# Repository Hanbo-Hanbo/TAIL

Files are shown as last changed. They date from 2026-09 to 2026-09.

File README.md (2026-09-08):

# TAIL

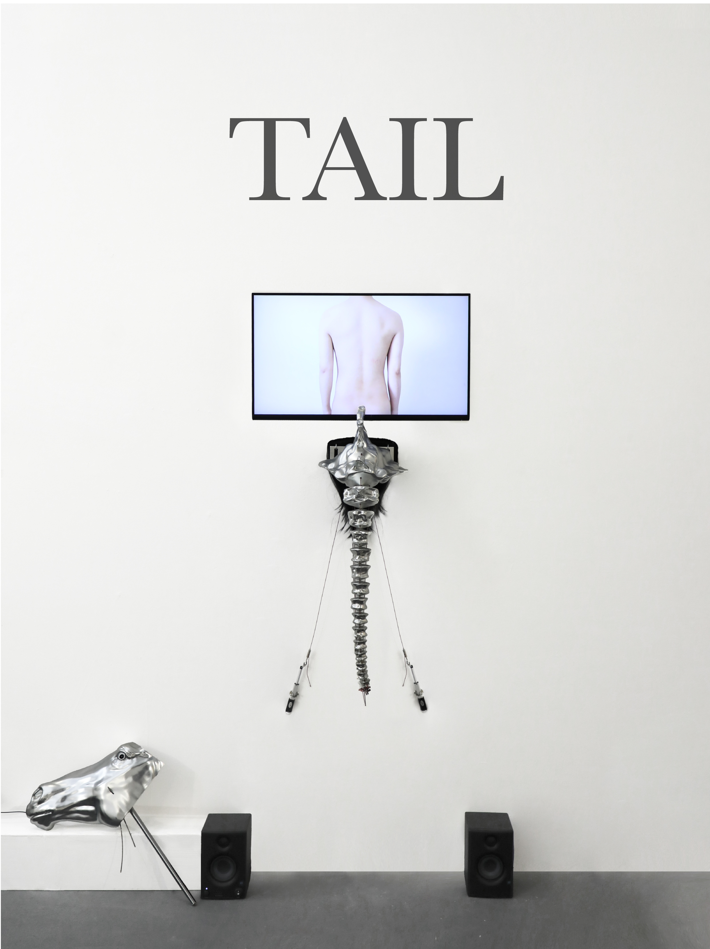
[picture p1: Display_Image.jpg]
TAIL installation


video link：https://youtu.be/1DqyYlydZfU

TAIL is a critical media art project that explores the power dynamics between technological systems and human subjectivity. The project consists of two parts: a live performance with a wearable device and an interactive physical installation.

The research motivation of this project is to ask: in a system that pursues extreme efficiency, how are humans gradually marginalized and ultimately abandoned? By constructing a spatial narrative from "physical discipline" to "machine takeover," the work visually presents this process of deprivation. When algorithms make decisions for humans in advance to eliminate latency, human-specific hesitation, thinking, and reaction time are defined by the system as inefficient defects that must be eradicated. Ultimately, this system, in its pursuit of absolute efficiency, not only replaces human physical labor but also directly eliminates the free will upon which humanity relies.

## 1. Hardware Components Required

Computer (Mac), webcam, Arduino UNO, L298N motor driver module, 12V telescoping motors (linear actuators), 12V motor power supply, USB data cable, jumper wires, speakers, monitor/display.

## 2. Software to Install

### 2.1 Python and its dependencies
First make sure Python 3 is installed (macOS usually ships with `python3`). Then install the dependencies in a terminal:

```bash
pip3 install opencv-python pyserial sounddevice numpy
```

- `opencv-python`: camera capture, face detection, video playback
- `pyserial`: controls the motors over the serial port (if missing, the program still runs but will not control the motors)
- `sounddevice` + `numpy`: real-time sound synthesis and audio output (if missing, the program still runs but produces no sound)

### 2.2 Arduino IDE
Download and install the Arduino IDE from the official website.

## 3. Wiring

### Control lines (Arduino -> L298N)
- Motor A (right): Arduino pin 4 -> L298N IN1, pin 5 -> IN2
- Motor B (left): Arduino pin 6 -> L298N IN3, pin 7 -> IN4

### Motor outputs (L298N -> motors)
- Motor A -> OUT1 / OUT2
- Motor B -> OUT3 / OUT4

### Power and ground 
- Connect the L298N motor-power input to the 12V supply positive terminal; connect the supply negative terminal to the L298N GND.
- The L298N GND must be tied together with the Arduino GND.
- Both the ENA and ENB enable jumpers on the L298N must be kept in place.

## 4. Flashing the Arduino

1. Connect the Arduino to the computer with a USB cable.
2. Open the Arduino IDE and open `Arduino.ino`.
3. Select your actual board model.
4. Click Upload and wait for "Done uploading".

## 5. Running the Program

Run `final.py` to start.

## 6. AI Usage Declaration

I hereby declare that the conceptual framework, theoretical research, and all visual and hardware designs for the TAIL project were conceived and completed entirely independently by me.

During the technical implementation phase, I utilized Artificial Intelligence tools as supplementary coding assistants. Specifically, AI was employed to help construct the Exponential Moving Average (EMA) algorithm within the Python script. This assistance was crucial in accurately calculating the velocity vectors of the audience's movements and successfully implementing the directional positioning for the predictive points.

Furthermore, I consulted AI tools as a debugging resource to help resolve two highly complex technical issues during system integration:

Implementing the non-blocking real-time audio synthesis callback using numpy and sounddevice, ensuring the dynamic overtone and distortion generation did not freeze the main computer vision loop.

Designing the control logic to strictly prevent the two telescoping motors from operating simultaneously. AI assisted in structuring a robust state machine that ensures one motor must completely finish its entire movement sequence before the other can be activated, effectively preventing structural damage to the physical installation.

All AI-assisted code was thoroughly reviewed, tested, and adapted by me to ensure it strictly served the project's core critical and artistic vision.

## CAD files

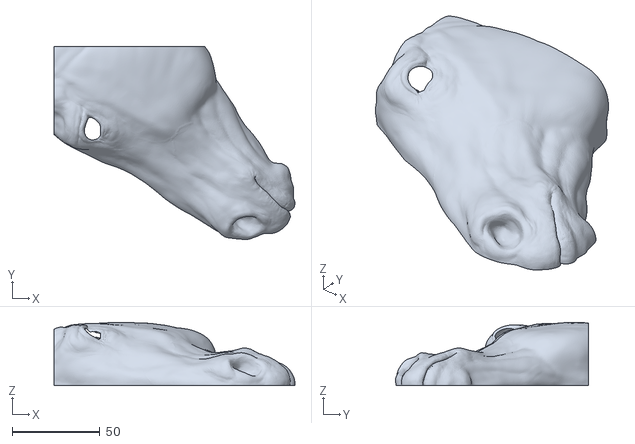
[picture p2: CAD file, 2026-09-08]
Model_file/Horse2.stl
137.4 x 110.0 x 36.0

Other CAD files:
Model_file/tail.stl

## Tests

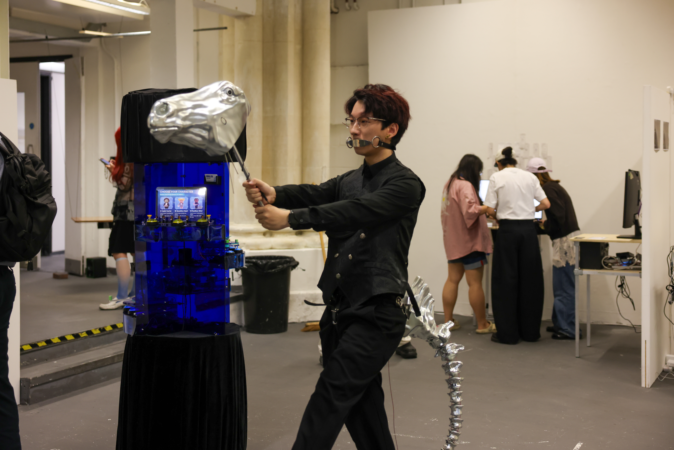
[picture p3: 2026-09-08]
Project_Images/Live_performance_photos2.jpg

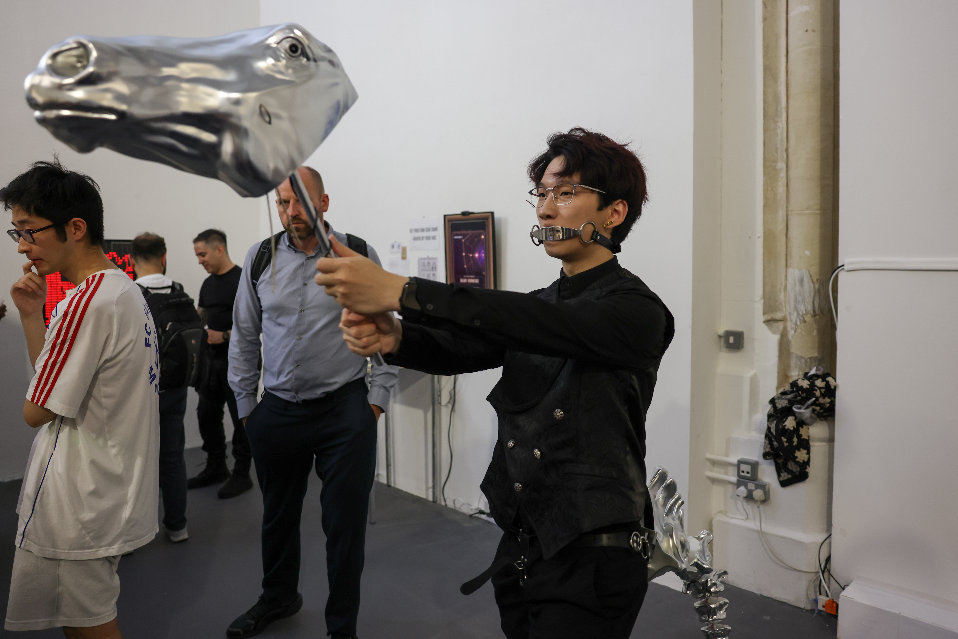
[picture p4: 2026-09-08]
Project_Images/Live_performance_photos.jpg

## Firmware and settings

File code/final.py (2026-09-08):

import cv2
import time
import sys
import os
import glob
import random


# Auto-scan for an available Arduino serial port; return None if not found
def autodetect_port():  
    """Auto-detect a connected Arduino serial port"""
    cands = sorted(
        glob.glob('/dev/cu.usbmodem*') + glob.glob('/dev/cu.usbserial*') +
        glob.glob('/dev/tty.usbmodem*') + glob.glob('/dev/ttyACM*') + glob.glob('/dev/ttyUSB*'))
    return cands[0] if cands else None

try:
    # Serial library: used to control the motor; warns if absent but still runs for testing
    import serial  # pip3 install pyserial
    SERIAL_AVAILABLE = True
except ImportError:
    SERIAL_AVAILABLE = False

try:
    # Libraries for sound synthesis: numpy for math, sounddevice for real-time audio
    import numpy as np
    import sounddevice as sd  # pip3 install sounddevice numpy
    SOUND_AVAILABLE = True
except Exception:
    SOUND_AVAILABLE = False


# Does not affect functionality; only makes the terminal output look nice
class Colors:
    GREEN = '\033[92m'
    RED = '\033[91m'
    GREY = '\033[90m'
    YELLOW = '\033[93m'
    BLUE = '\033[94m'
    RESET = '\033[0m'


C = {
    'GREEN': Colors.GREEN, 'RED': Colors.RED, 'GREY': Colors.GREY,
    'YELLOW': Colors.YELLOW, 'BLUE': Colors.BLUE, 'RESET': Colors.RESET
}


# Continuously synthesize and output sound from people count / motion / prediction-failure
class SoundEngine:
    # sample rate, block size, people needed for max breakdown, and synthesis state variables
    def __init__(self, enabled=True, max_faces=5, samplerate=44100, blocksize=1024):
        self.enabled = enabled and SOUND_AVAILABLE
        self.sr = samplerate
        self.bs = blocksize
        self.max_faces = max(1, max_faces)

        # Overtone multipliers vs. the base pitch, and the detune applied to overtones when prediction fails
        self.ratios = None       # Consonant interval ratios 
        self.inharm = None       # Per-overtone detune amount driven by discord

        
        self.tgt_intensity = 0.0
        self.tgt_motion = 0.0
        self.tgt_discord = 0.0
        self.cur_intensity = 0.0
        self.cur_motion = 0.0
        self.cur_discord = 0.0
        self.master = 0.0# master volume

        self.part_phase = None
        self.lfo_phase = 0.0
        self.trem_phase = 0.0
        self.drift_phase = 0.0
        self.stream = None

        if enabled and not SOUND_AVAILABLE:
            print(f"{C['YELLOW']}sounddevice/numpy not installed, sound disabled (pip3 install sounddevice numpy){C['RESET']}")

    
    # Open camera, start sound
    def start(self):
        if not self.enabled:
            return
        try:
            self.ratios = np.array([1.0, 1.5, 2.0, 2.5, 3.0, 4.0])
            self.inharm = np.array([0.0, 0.030, -0.025, 0.050, -0.040, 0.060])
            self.part_phase = np.zeros(len(self.ratios))
            self.stream = sd.OutputStream(
                samplerate=self.sr, channels=1, blocksize=self.bs,
                dtype='float32', callback=self._callback)
            self.stream.start()
            print(f"{C['GREEN']}Sound started{C['RESET']}")
        except Exception as e:
            print(f"{C['RED']}Sound start failed: {e}{C['RESET']}")
            self.enabled = False

    # Normalize people count / motion / prediction-failure and write to target parameters
    def update(self, face_count, motion, discord):
        self.tgt_intensity = min(1.0, face_count / float(self.max_faces))
        self.tgt_motion = max(0.0, min(1.0, motion))
        self.tgt_discord = max(0.0, min(1.0, discord))

    # Called automatically at high frequency by the audio thread
    def _callback(self, outdata, frames, time_info, status):
        sr = self.sr
        a = 0.08
        self.cur_intensity += (self.tgt_intensity - self.cur_intensity) * a
        self.cur_motion += (self.tgt_motion - self.cur_motion) * a
        self.cur_discord += (self.tgt_discord - self.cur_discord) * a
        # Target volume is 0 (mute) when no one is present , else 0.9; master
        target_master = 0.0 if self.tgt_intensity <= 0.001 else 0.9
        self.master += (target_master - self.master) * 0.03
        inten = self.cur_intensity
        mot = self.cur_motion
        dis = self.cur_discord

        n = np.arange(1, frames + 1)
        two_pi_sr = 2 * np.pi / sr

        # Slow random drift
        drift_inc = 2 * np.pi * 0.05 / sr
        drift = np.sin(self.drift_phase + drift_inc * n)
        self.drift_phase = (self.drift_phase + drift_inc * frames) % (2 * np.pi)

    
        # Base pitch rises with people: ~80Hz when few, ~220Hz when many, times a slow drift for variation
        base_pitch = (80.0 + inten * 140.0) * (1.0 + 0.03 * drift)

        # Vibrato
        vib_rate = 4.0 + mot * 8.0
        vib_inc = 2 * np.pi * vib_rate / sr
        lfo = np.sin(self.lfo_phase + vib_inc * n)
        self.lfo_phase = (self.lfo_phase + vib_inc * frames) % (2 * np.pi)
        # The more motion, the deeper the vibrato
        f_base = base_pitch * (1.0 + (0.008 + mot * 0.05) * lfo)

        # Accumulate
        sig = np.zeros(frames)
        NP = len(self.ratios)
        # The higher the discord, the more detuned and harsh the overtones 
        for k in range(NP):
            ratio = self.ratios[k] * (1.0 + dis * self.inharm[k])
            phase = self.part_phase[k] + two_pi_sr * np.cumsum(f_base * ratio)
            self.part_phase[k] = phase[-1] % (2 * np.pi)
            presence = np.clip(inten * NP - k, 0.0, 1.0)   # The more people, the fuller the overtones
            sig += (1.0 / (k + 1)) * presence * np.sin(phase)
        sig *= 0.28

        # Distortion: increases with discord
        # The more prediction fails, the more the sound breaks down
        if dis > 0.001:
            sig += (dis * 0.30) * (np.random.rand(frames) * 2 - 1)
        drive = 1.0 + dis * 8.0
        sig = np.tanh(sig * drive) / np.tanh(drive)

        
        trem_rate = 6.0 + mot * 10.0
        trem_inc = 2 * np.pi * trem_rate / sr
        trem = np.sin(self.trem_phase + trem_inc * n)
        self.trem_phase = (self.trem_phase + trem_inc * frames) % (2 * np.pi)
        sig *= (1.0 - (mot * 0.5) * (0.5 + 0.5 * trem))

        # Clip to [-1,1] to prevent clipping, plus buffering
        sig *= self.master
        np.clip(sig, -1.0, 1.0, out=sig)
        outdata[:, 0] = sig.astype(np.float32)

    # Stop and close the audio stream
    def stop(self):
        if self.stream is not None:
            try:
                self.stream.stop(); self.stream.close()
            except Exception:
                pass
            self.stream = None



# White fade in/out on loop or clip change
class VideoPlayer:
    PLAY, FADEOUT, FADEIN = 0, 1, 2

    def __init__(self, enabled=True, fullscreen=True, window="Video", fade_dur=0.4):
        self.enabled = enabled
        self.fullscreen = fullscreen
        self.window = window
        self.fade_dur = fade_dur
        self.cap = None
        self.current = None
        self.target = None
        self.fps = 5.0
        self.speed = 1.0
        self.win_created = False
        self.warned = set()
        self.state = self.PLAY
        self.last = None
        self.next_read = 0.0
        self.fade_start = 0.0
        self.total_frames = 0
        self.frame_idx = 0
        self._looped = False

    # Set the current video file to play; a different one triggers a clip transition
    def set_target(self, path):
        self.target = path

    # Return the current video playback progress
    def progress(self):
        return (self.frame_idx / self.total_frames) if self.total_frames > 0 else 0.0

    # Loop or clip change
    def pop_loop(self):
        r = self._looped
        self._looped = False
        return r

    # Fullscreen
    def _ensure_window(self):
        if not self.win_created:
            cv2.namedWindow(self.window, cv2.WINDOW_NORMAL)
            if self.fullscreen:
                cv2.setWindowProperty(self.window, cv2.WND_PROP_FULLSCREEN, cv2.WINDOW_FULLSCREEN)
            self.win_created = True

    # Fade in/out uses solid white
    def _fade_like(self, frame):
        import numpy as _np
        return _np.full_like(frame, 255)  

    # Open the video file
    def _open(self, path):
        if self.cap is not None:
            self.cap.release()
            self.cap = None
        cap = cv2.VideoCapture(path)
        if not cap.isOpened():
            if path not in self.warned:
                print(f"{C['YELLOW']}Cannot open video: {path}{C['RESET']}")
                self.warned.add(path)
            self.cap = None
            self.current = path
            self.total_frames = 0
            self.frame_idx = 0
            return False
        self.cap = cap
        self.current = path
        f = cap.get(cv2.CAP_PROP_FPS)
        self.fps = f if f and f > 0 else 5.0
        self.total_frames = int(cap.get(cv2.CAP_PROP_FRAME_COUNT)) or 0
        self.frame_idx = 0
        return True

    # Play at real speed
    def _interval(self):
        return 1.0 / (self.fps * max(0.1, self.speed))

    # Display a frame according to the state machine
    def render(self):
        if not self.enabled:
            return
        self._ensure_window()
        now = time.time()

        if self.cap is None and self.current is None and self.target is not None:
            if self._open(self.target):
                ret, f = self.cap.read()
                if ret:
                    self.last = f
                    self.frame_idx += 1
                    self.next_read = now + self._interval()
                self.state = self.FADEIN
                self.fade_start = now
            else:
                return

        disp = None

        # If the target clip changed, fade out; when finished, fade out then loop
        if self.state == self.PLAY:
            if self.target is not None and self.target != self.current:
                self.state = self.FADEOUT
                self.fade_start = now
                disp = self.last
            else:
                if now >= self.next_read and self.cap is not None:
                    ret, f = self.cap.read()
                    if ret:
                        self.last = f
                        self.frame_idx += 1
                        self.next_read = now + self._interval()
                    else:
                        self.state = self.FADEOUT
                        self.fade_start = now
                disp = self.last

        # Fade out
        elif self.state == self.FADEOUT:
            if self.last is None:
                self.state = self.FADEIN
                self.fade_start = now
            else:
                pr = min(1.0, (now - self.fade_start) / self.fade_dur)
                fadecol = self._fade_like(self.last)
                disp = cv2.addWeighted(self.last, 1.0 - pr, fadecol, pr, 0)
                if pr >= 1.0:
                    nxt = self.target if (self.target and self.target != self.current) else self.current
                    self._open(nxt)
                    self._looped = True     # Loop or clip change
                    if self.cap is not None:
                        ret, f = self.cap.read()
                        if ret:
                            self.last = f
                            self.frame_idx += 1
                            self.next_read = now + self._interval()
                    self.state = self.FADEIN
                    self.fade_start = now

        # Fade in
        elif self.state == self.FADEIN:
            if self.last is None:
                self.state = self.PLAY
            else:
                pr = min(1.0, (now - self.fade_start) / self.fade_dur)
                fadecol = self._fade_like(self.last)
                disp = cv2.addWeighted(fadecol, 1.0 - pr, self.last, pr, 0)
                if pr >= 1.0:
                    self.state = self.PLAY
                    self.next_read = now + self._interval()

        if disp is not None:
            cv2.imshow(self.window, disp)

    # Toggle fullscreen / windowed display
    def toggle_fullscreen(self):
        self.fullscreen = not self.fullscreen
        if self.win_created:
            cv2.setWindowProperty(
                self.window, cv2.WND_PROP_FULLSCREEN,
                cv2.WINDOW_FULLSCREEN if self.fullscreen else cv2.WINDOW_NORMAL)

    # Release video resources
    def close(self):
        if self.cap is not None:
            self.cap.release()
            self.cap = None



# 'E' = trigger, 'S' = home
class MotorController:
    def __init__(self, port='/dev/cu.usbmodem', baud=9600, enabled=True):
        self.port = port
        self.baud = baud
        self.ser = None
        self.enabled = enabled and SERIAL_AVAILABLE
        if enabled and not SERIAL_AVAILABLE:
            print(f"{C['YELLOW']}pyserial not installed, motor control disabled (pip3 install pyserial){C['RESET']}")
            return
        if self.enabled:
            self._connect()

    # Open the serial port and wait for the Arduino; failure does not affect other parts
    def _connect(self):
        try:
            self.ser = serial.Serial(self.port, self.baud, timeout=1)
            time.sleep(2)
            print(f"{C['GREEN']}Motor serial connected: {self.port} @ {self.baud}{C['RESET']}")
        except Exception as e:
            print(f"{C['RED']}Cannot open serial port {self.port}: {e}{C['RESET']}")
            print(f"{C['GREY']}  Program keeps running but will not control the motor{C['RESET']}")
            self.ser = None
            self.enabled = False

    # Trigger one motor action
    def move(self):
        self._send(b'E')        # This firmware: 'E' triggers one alternating action from IDLE

    def person_left(self):
        self._send(b'S')        # no person

    # Read debug info printed back by the Arduino
    def read_debug(self):
        """check which motor the firmware is driving"""
        lines = []
        if self.ser and self.ser.is_open:
            try:
                while self.ser.in_waiting:
                    ln = self.ser.readline().decode('utf-8', 'ignore').strip()
                    if ln:
                        lines.append(ln)
            except Exception:
                pass
        return lines

    # Write bytes to the serial port
    def _send(self, data):
        if self.ser and self.ser.is_open:
            try:
                self.ser.write(data)
            except Exception as e:
                print(f"{C['RED']}Serial send failed: {e}{C['RESET']}")

    # Home the motor before closing the serial port on exit
    def close(self):
        if self.ser and self.ser.is_open:
            try:
                self.person_left()
                time.sleep(0.1)
                self.ser.close()
                print(f"{C['GREY']}Motor serial closed{C['RESET']}")
            except Exception:
                pass
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

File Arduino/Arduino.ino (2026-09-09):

// Pins for motors A and B
int P1[2] = {4, 6};   // IN1
int P2[2] = {5, 7};   // IN2
bool INV[2] = {false, false};


const unsigned long RETRACT_MS  = 5000;   // Retract duration per action
const unsigned long EXTEND_MS   = 5000;   // Extend-back (home) duration
const unsigned long INTERVAL_MS = 10000;  // Pause between two actions (10 seconds)
const unsigned long HOME_MS     = 5000;   // Power-on homing: both extend out

// State machine
enum { IDLE, RETRACT, EXTEND, WAIT };
byte phase = IDLE;
int curMotor = 1;            // Used for alternating; first action makes it 0 (motor A)
unsigned long phaseStart = 0;

bool personPresent = false;


void mExtend(int i) {
  if (INV[i]) { digitalWrite(P1[i], LOW);  digitalWrite(P2[i], HIGH); }
  else        { digitalWrite(P1[i], HIGH); digitalWrite(P2[i], LOW);  }
}
void mRetract(int i) {
  if (INV[i]) { digitalWrite(P1[i], HIGH); digitalWrite(P2[i], LOW);  }
  else        { digitalWrite(P1[i], LOW);  digitalWrite(P2[i], HIGH); }
}
void mHold(int i) { digitalWrite(P1[i], LOW); digitalWrite(P2[i], LOW); }

void setup() {
  Serial.begin(9600);
  delay(50);
  Serial.println("=== FW: A=2/3 B=4/5 | one-at-a-time ===");

  for (int i = 0; i < 2; i++) { pinMode(P1[i], OUTPUT); pinMode(P2[i], OUTPUT); }

  // Power-on homing: both extend out
  mExtend(0); mExtend(1);
  delay(HOME_MS);
  mHold(0); mHold(1);
  phase = IDLE;

  Serial.println("READY");
}

void loop() {
  while (Serial.available() > 0) {
    char c = Serial.read();
    if (c == 'E') personPresent = true;
    else if (c == 'S') personPresent = false;
  }

  unsigned long now = millis();

  switch (phase) {
    case IDLE:
      if (personPresent) {                 // Person detected: start the first action immediately
        curMotor = 1 - curMotor;           // Alternate
        mRetract(curMotor);
        phase = RETRACT; phaseStart = now;
        Serial.print("Action "); Serial.print(curMotor == 0 ? "A" : "B"); Serial.println(" retract");
      }
      break;

    case RETRACT:
      // Nobody present partway through: just extend back home
      if (!personPresent) { mExtend(curMotor); phase = EXTEND; phaseStart = now; break; }
      if (now - phaseStart >= RETRACT_MS) {
        mExtend(curMotor);                 // Retract done: extend back home
        phase = EXTEND; phaseStart = now;
      }
      break;

    case EXTEND:
      if (now - phaseStart >= EXTEND_MS) {
        mHold(curMotor);                   // Back at extended position, stop
        phase = WAIT; phaseStart = now;
      }
      break;

    case WAIT:
      if (!personPresent) { phase = IDLE; break; }
      if (now - phaseStart >= INTERVAL_MS) {   // After the 10s interval, switch to the other motor
        curMotor = 1 - curMotor;
        mRetract(curMotor);
        phase = RETRACT; phaseStart = now;
        Serial.print("Action"); Serial.print(curMotor == 0 ? "A" : "B"); Serial.println(" retract");
      }
      break;
  }
}
